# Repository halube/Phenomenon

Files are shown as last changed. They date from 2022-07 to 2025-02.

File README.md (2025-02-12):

# Phenomenon - Low-cost and multi-sensor system for automated phenotyping of plant in vitro culture
This is the official code implementation and used hardware of our paper, which is currently under a journal review:

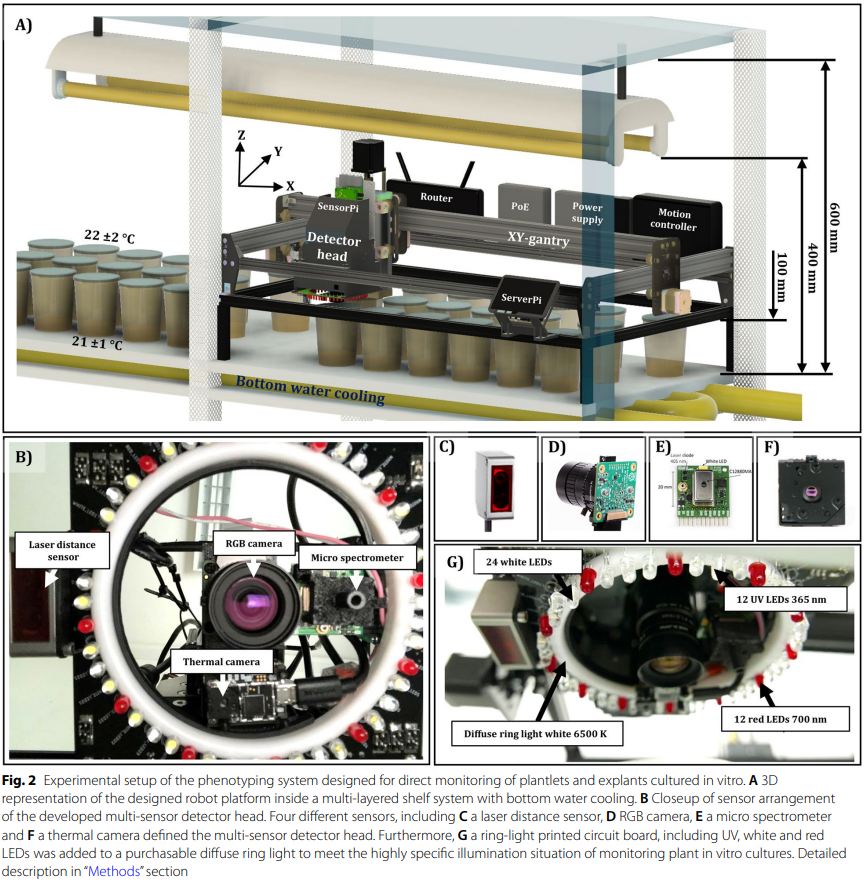
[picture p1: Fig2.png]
Robot


The main mechanical components of the system were:
- OpenBuilds ACRO 1515 60" x 60" (XY gantry)
- Openbuilds Linear Actuator (Z axis)

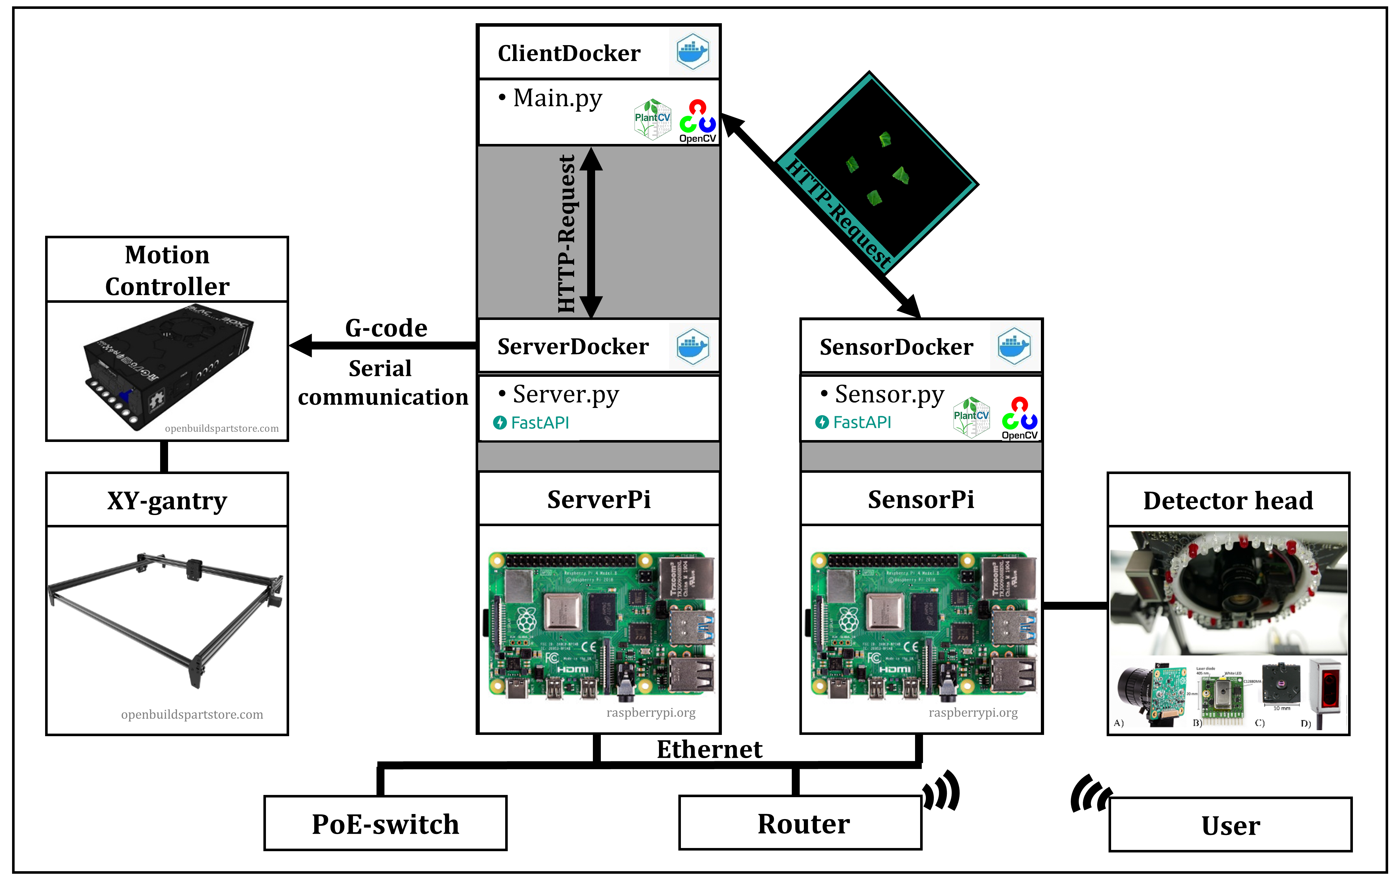
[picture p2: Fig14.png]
Software


Network connection & embedded system:
- Router & PoE-Switch
- 2 x Raspberry Pi 4B & PoE-Shield
- 2 x Wemos D1 Mini

Sensors of the system:
- RGB Raspberry Pi Camera High quality 12 MB with Edmund Optics 6mm low distortion lens equipied
- Thermal PureThermal 2 & Lepton 3.5
- Spectral µSpectrometer Hamamatsu C12880MA
- Depth Laser distance sensor OD-Mini OB1-B100

Hardware
- Containing 3D printable parts and PCB-Layouts

Software
- Containing Dockerfiles and Python scripts

Cite:
Bethge H, Winkelmann T, Lüdeke P, Rath T. Low-cost and automated phenotyping system “Phenomenon” for multi-sensor in situ monitoring in plant in vitro culture. Plant methods. 2023 May 2;19(1):42.

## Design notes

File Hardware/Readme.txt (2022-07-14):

Some of the 3D printed parts for cable chain were inspired by the build of "hilleke" & "dragonfire81m" 
(Thingiverse-User: https://www.thingiverse.com/thing:3110642; https://www.thingiverse.com/thing:2780302) but mainly also modified.

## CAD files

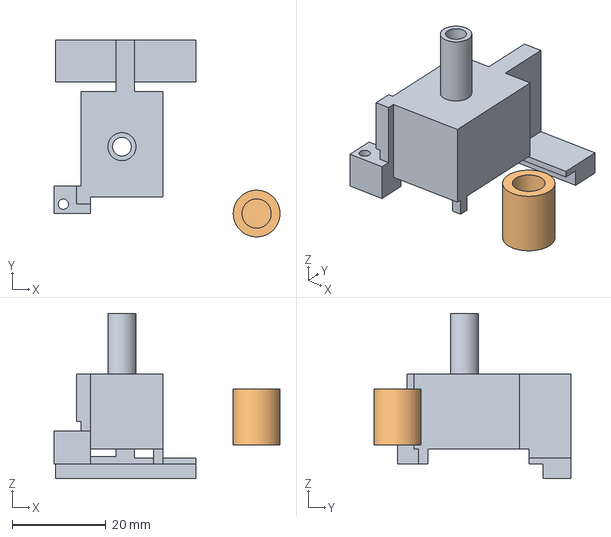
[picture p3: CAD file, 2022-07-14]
Hardware/MicroSpectrometer_Tube_aperature.step
48.2 x 42.0 x 35.3 mm

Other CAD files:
Hardware/X-Axis Cable chain and Motor retainer.f3d
Hardware/Y-Axis Cable chain retainer.f3d
Hardware/Y2-Axis Cable chain and Motor retainer.f3d

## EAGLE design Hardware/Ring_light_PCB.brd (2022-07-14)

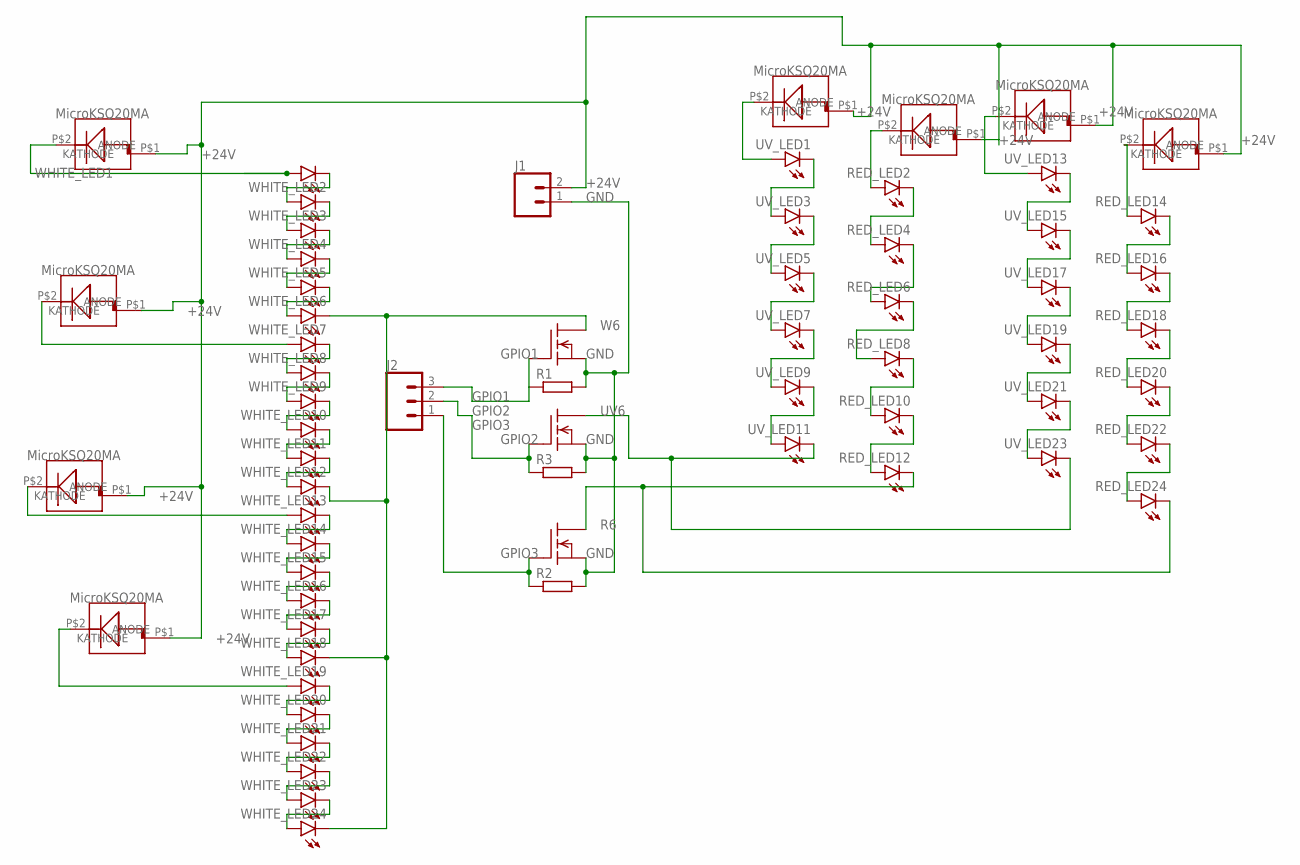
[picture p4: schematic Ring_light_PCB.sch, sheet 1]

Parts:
J1: CONN_025MM; SCREWTERMINAL-5MM-2
J2: CONN_03-SCREW-5MM; SCREWTERMINAL-5MM-3
Q1, Q2, Q4: BUZ10; TO220
R1, R2, R3: R-EU_0204/7; 0204/7
RED_LED2, RED_LED4, RED_LED6, RED_LED8, RED_LED10, RED_LED12, RED_LED14, RED_LED16, RED_LED18, RED_LED20, RED_LED22, RED_LED24: LED5MM
U$1, U$2, U$3, U$4, U$5, U$6, U$7, U$8: MICROKSQ220MA; MICROKSQ20MA
UV_LED1, UV_LED3, UV_LED5, UV_LED7, UV_LED9, UV_LED11, UV_LED13, UV_LED15, UV_LED17, UV_LED19, UV_LED21, UV_LED23: LED5MM
WHITE_LED1, WHITE_LED2, WHITE_LED3, WHITE_LED4, WHITE_LED5, WHITE_LED6, WHITE_LED7, WHITE_LED8, WHITE_LED9, WHITE_LED10, WHITE_LED11, WHITE_LED12, WHITE_LED13, WHITE_LED14, WHITE_LED15, WHITE_LED16, WHITE_LED17, WHITE_LED18, WHITE_LED19, WHITE_LED20, WHITE_LED21, WHITE_LED22, WHITE_LED23, WHITE_LED24: LED5MM

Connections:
+24V: J1.2, U$1.P$1 (KATHODE), U$2.P$1 (KATHODE), U$3.P$1 (KATHODE), U$4.P$1 (KATHODE), U$5.P$1 (KATHODE), U$6.P$1 (KATHODE), U$7.P$1 (KATHODE), U$8.P$1 (KATHODE)
GND: J1.1, Q1.3 (S), Q2.3 (S), Q4.3 (S), R1.2, R2.2, R3.2
GPIO1: J2.3, Q1.1 (G), R1.1
GPIO2: J2.2, Q2.1 (G), R3.1
GPIO3: J2.1, Q4.1 (G), R2.1
R0: RED_LED2.A, U$8.P$2 (ANODE)
R1: RED_LED2.K (C), RED_LED4.A
R2: RED_LED4.K (C), RED_LED6.A
R3: RED_LED6.K (C), RED_LED8.A
R4: RED_LED8.K (C), RED_LED10.A
R5: RED_LED10.K (C), RED_LED12.A
R6: Q4.2 (D), RED_LED12.K (C), RED_LED24.K (C)
R7: RED_LED14.A, U$6.P$2 (ANODE)
R8: RED_LED14.K (C), RED_LED16.A
R9: RED_LED16.K (C), RED_LED18.A
R10: RED_LED18.K (C), RED_LED20.A
R11: RED_LED20.K (C), RED_LED22.A
R12: RED_LED22.K (C), RED_LED24.A
UV0: U$7.P$2 (ANODE), UV_LED1.A
UV1: UV_LED1.K (C), UV_LED3.A
UV2: UV_LED3.K (C), UV_LED5.A
UV3: UV_LED5.K (C), UV_LED7.A
UV4: UV_LED7.K (C), UV_LED9.A
UV5: UV_LED9.K (C), UV_LED11.A
UV6: Q2.2 (D), UV_LED11.K (C), UV_LED23.K (C)
UV7: U$5.P$2 (ANODE), UV_LED13.A
UV8: UV_LED13.K (C), UV_LED15.A
UV9: UV_LED15.K (C), UV_LED17.A
UV10: UV_LED17.K (C), UV_LED19.A
UV11: UV_LED19.K (C), UV_LED21.A
UV12: UV_LED21.K (C), UV_LED23.A
W0: U$1.P$2 (ANODE), WHITE_LED1.A
W1: WHITE_LED1.K (C), WHITE_LED2.A
W2: WHITE_LED2.K (C), WHITE_LED3.A
W3: WHITE_LED3.K (C), WHITE_LED4.A
W4: WHITE_LED4.K (C), WHITE_LED5.A
W5: WHITE_LED5.K (C), WHITE_LED6.A
W6: Q1.2 (D), WHITE_LED6.K (C), WHITE_LED12.K (C), WHITE_LED18.K (C), WHITE_LED24.K (C)
W7: U$2.P$2 (ANODE), WHITE_LED7.A
W8: WHITE_LED7.K (C), WHITE_LED8.A
W9: WHITE_LED8.K (C), WHITE_LED9.A
W10: WHITE_LED9.K (C), WHITE_LED10.A
W11: WHITE_LED10.K (C), WHITE_LED11.A
W12: WHITE_LED11.K (C), WHITE_LED12.A
W13: U$3.P$2 (ANODE), WHITE_LED13.A
W14: WHITE_LED13.K (C), WHITE_LED14.A
W15: WHITE_LED14.K (C), WHITE_LED15.A
W16: WHITE_LED15.K (C), WHITE_LED16.A
W17: WHITE_LED16.K (C), WHITE_LED17.A
W18: WHITE_LED17.K (C), WHITE_LED18.A
W19: U$4.P$2 (ANODE), WHITE_LED19.A
W20: WHITE_LED19.K (C), WHITE_LED20.A
W21: WHITE_LED20.K (C), WHITE_LED21.A
W22: WHITE_LED21.K (C), WHITE_LED22.A
W23: WHITE_LED22.K (C), WHITE_LED23.A
W24: WHITE_LED23.K (C), WHITE_LED24.A

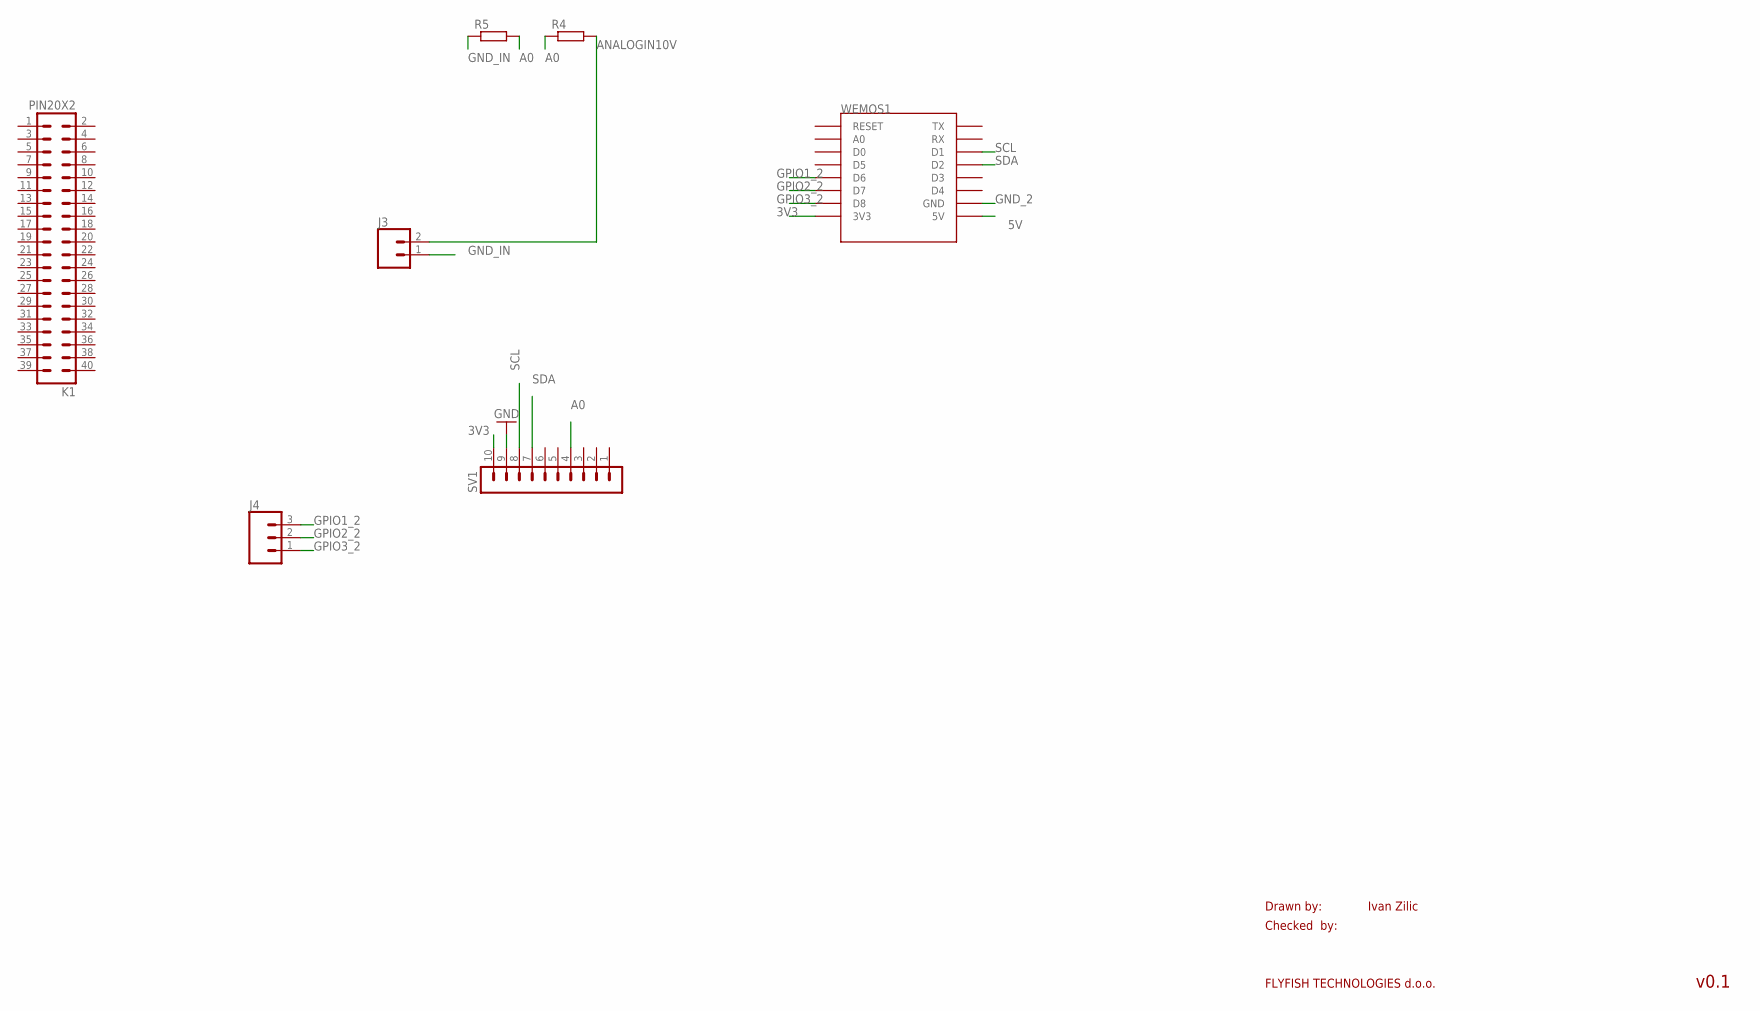
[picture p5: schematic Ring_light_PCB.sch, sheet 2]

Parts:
J3: CONN_025MM; SCREWTERMINAL-5MM-2
J4: CONN_03-SCREW-5MM; SCREWTERMINAL-5MM-3
K1: PIN20X2; PIN_20X2
R4, R5: R-EU_0204/7; 0204/7
SV1: MA10-1
WEMOS1: WEMOS-D1-MINI

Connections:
3V3: SV1.10, WEMOS1.3V3
5V: WEMOS1.5V
A0: R4.1, R5.2, SV1.4
ANALOGIN10V: J3.2, R4.2
GND_2: SV1.9, WEMOS1.GND
GND_IN: J3.1, R5.1
GPIO1_2: J4.3, WEMOS1.D6
GPIO2_2: J4.2, WEMOS1.D7
GPIO3_2: J4.1, WEMOS1.D8
SCL: SV1.8, WEMOS1.D1
SDA: SV1.7, WEMOS1.D2

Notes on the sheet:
Drawn by:
Checked by:
FLYFISH TECHNOLOGIES d.o.o.
Ivan Zilic
v0.1

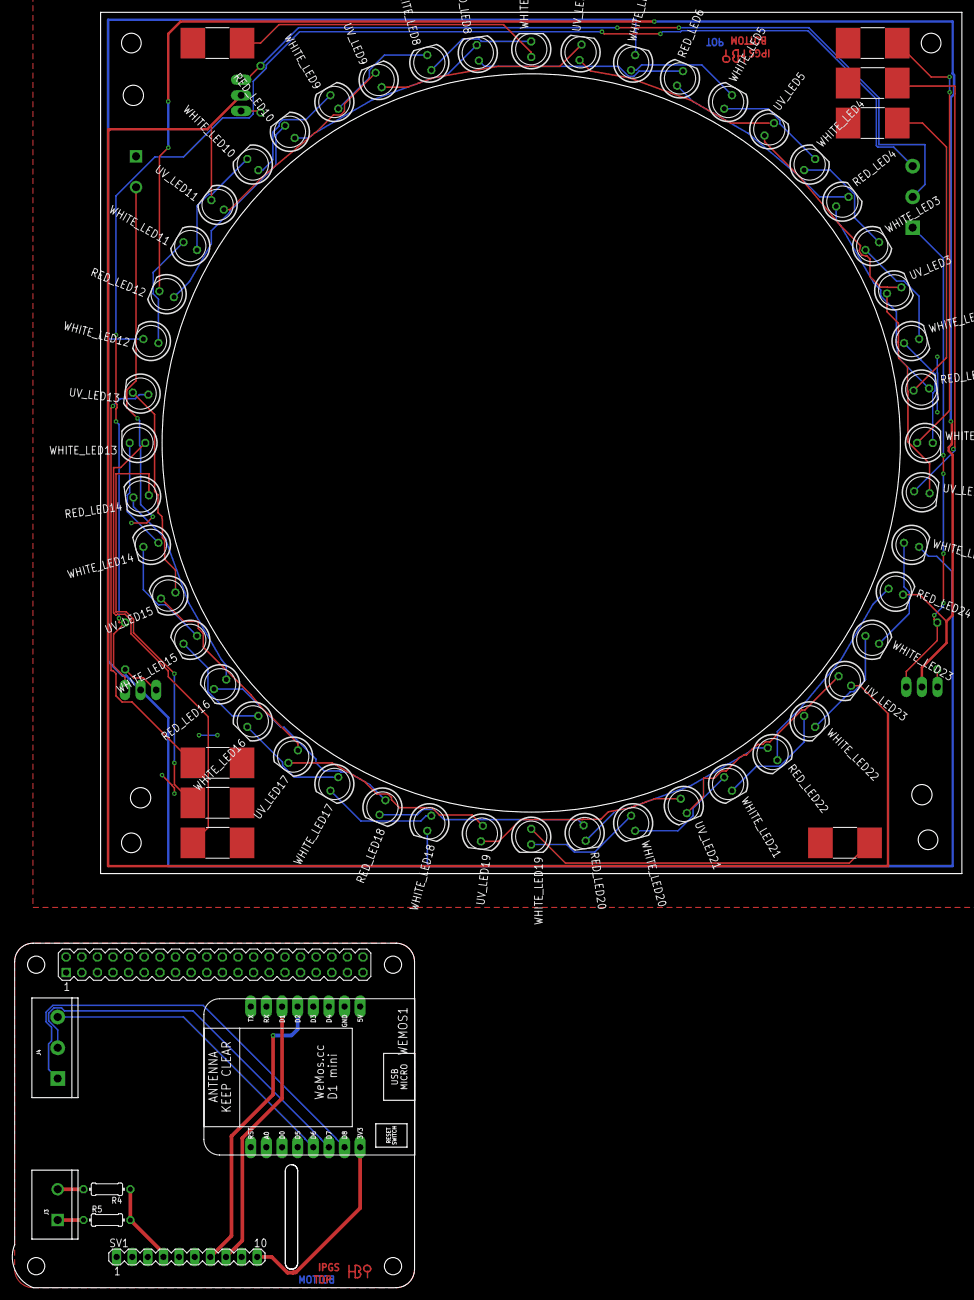
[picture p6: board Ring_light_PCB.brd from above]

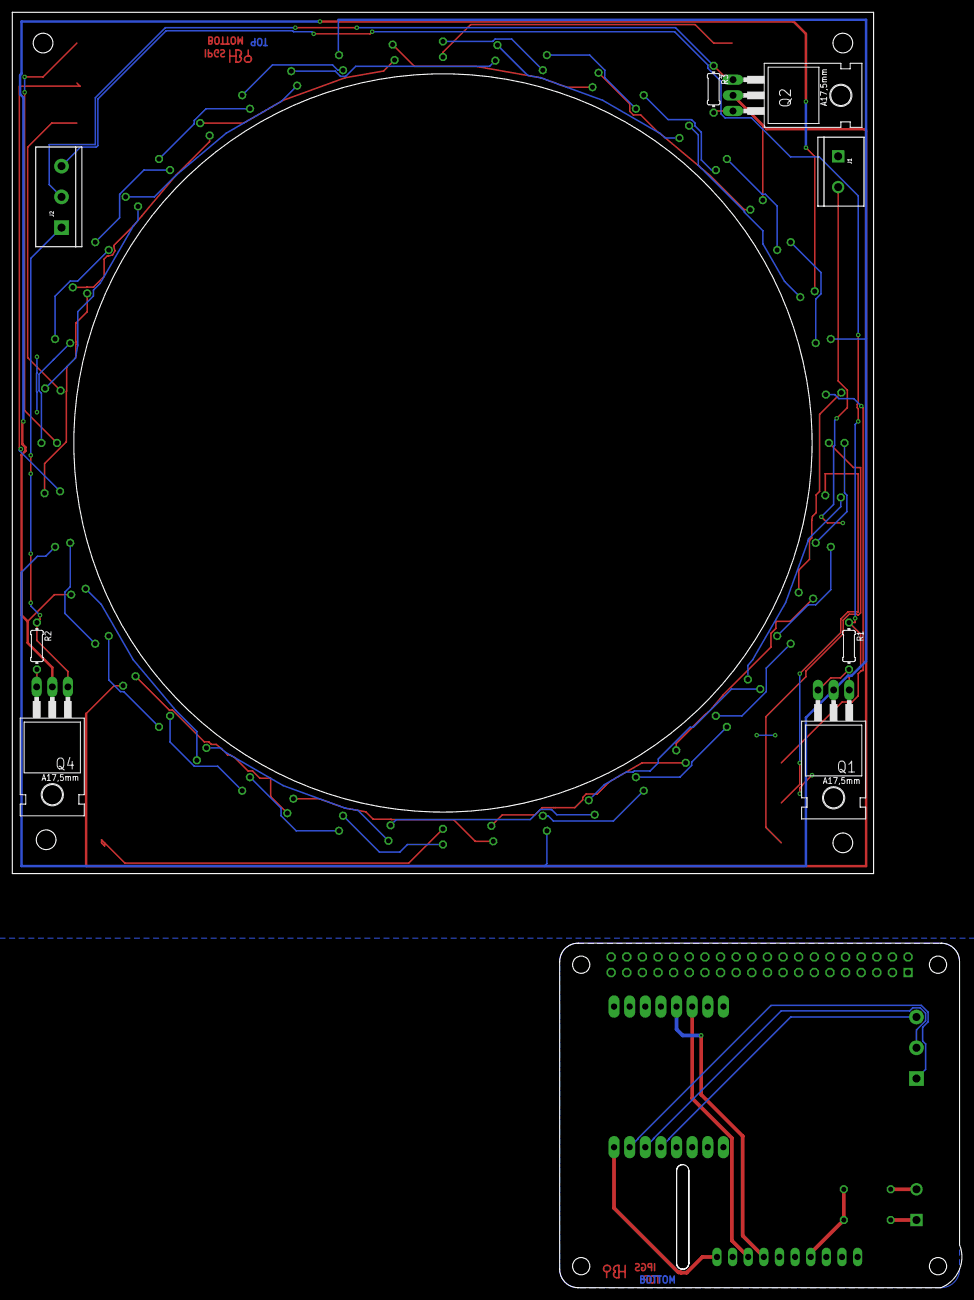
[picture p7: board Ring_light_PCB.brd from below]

Board: 2 copper layers, 140.0 x 140.0 mm, 71 parts (8 on the bottom side), 66 nets.

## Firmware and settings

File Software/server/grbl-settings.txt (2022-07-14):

$0=10  ;  Step pulse time, microseconds
$1=255  ;  Step idle delay, milliseconds
$2=0  ;  Step pulse invert, mask
$3=1  ;  Step direction invert, mask
$4=1  ;  Invert step enable pin, boolean
$5=0  ;  Invert limit pins, boolean
$6=0  ;  Invert probe pin, boolean
$10=1  ;  Status report options, mask
$11=0.020  ;  Junction deviation, millimeters
$12=0.002  ;  Arc tolerance, millimeters
$13=0  ;  Report in inches, boolean
$20=0  ;  Soft limits enable, boolean
$21=1  ;  Hard limits enable, boolean
$22=1  ;  Homing cycle enable, boolean
$23=3  ;  Homing direction invert, mask
$24=100.000  ;  Homing locate feed rate, mm/min
$25=1000.000  ;  Homing search seek rate, mm/min
$26=250  ;  Homing switch debounce delay, milliseconds
$27=5.000  ;  Homing switch pull-off distance, millimeters
$30=1000  ;  Maximum spindle speed, RPM
$31=0  ;  Minimum spindle speed, RPM
$32=0  ;  Laser-mode enable, boolean
$100=53.333  ;  X-axis steps per millimeter
$101=53.333  ;  Y-axis steps per millimeter
$102=200.000  ;  Z-axis steps per millimeter
$110=2500.000  ;  X-axis maximum rate, mm/min
$111=2500.000  ;  Y-axis maximum rate, mm/min
$112=1500.000  ;  Z-axis maximum rate, mm/min
$120=150.000  ;  X-axis acceleration, mm/sec^2
$121=150.000  ;  Y-axis acceleration, mm/sec^2
$122=50.000  ;  Z-axis acceleration, mm/sec^2
$130=660.000  ;  X-axis maximum travel, millimeters
$131=230.000  ;  Y-axis maximum travel, millimeters
$132=60.000  ;  Z-axis maximum travel, millimeters

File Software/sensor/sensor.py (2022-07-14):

#### Sensor.py description####
#### Author: Hans Bethge and Patrick Lüdeke
#### Description: Read sensors with Raspberry Pi 4 and network access of these function & data via FastAPI 
#### Required libraries:
from fastapi import FastAPI, HTTPException
from fastapi.middleware.cors import CORSMiddleware
from time import sleep
from fastapi.logger import logger
from picamera import PiCamera
from datetime import datetime, timedelta
from fastapi.responses import FileResponse, JSONResponse
import picamera
from picamera import mmal, mmalobj, exc
from picamera.mmalobj import to_rational
import time
import logging
import glob
import serial
import cv2
import numpy as np
from flirpy.camera.lepton import Lepton

try:
  from queue import Queue
except ImportError:
  from Queue import Queue
import platform


#### Set PiCamera HQ Gain controll
#### Credits to github.com/rwb27/set_picamera_gain.py
MMAL_PARAMETER_ANALOG_GAIN = mmal.MMAL_PARAMETER_GROUP_CAMERA + 0x59
MMAL_PARAMETER_DIGITAL_GAIN = mmal.MMAL_PARAMETER_GROUP_CAMERA + 0x5A
def setCameraGain(camera, gain, value):
    """Set the analog gain of a PiCamera.
    camera: the picamera.PiCamera() instance you are configuring
    gain: either MMAL_PARAMETER_ANALOG_GAIN or MMAL_PARAMETER_DIGITAL_GAIN
    value: a numeric value that can be converted to a rational number.
    """
    if gain not in [MMAL_PARAMETER_ANALOG_GAIN, MMAL_PARAMETER_DIGITAL_GAIN]:
        raise ValueError("The gain parameter was not valid")
    ret = mmal.mmal_port_parameter_set_rational(camera._camera.control._port, 
                                                    gain,
                                                    to_rational(value))
    if ret == 4:
        raise exc.PiCameraMMALError(ret, "Are you running the latest version of the userland libraries? Gain setting was introduced in late 2017.")
    elif ret != 0:
        raise exc.PiCameraMMALError(ret)

def setCameraAnalogGain(camera, value):
    """Set the gain of a PiCamera object to a given value."""
    setCameraGain(camera, MMAL_PARAMETER_ANALOG_GAIN, value)

def setCameraDigitalGain(camera, value):
    """Set the digital gain of a PiCamera object to a given value."""
    setCameraGain(camera, MMAL_PARAMETER_DIGITAL_GAIN, value)
#### Initialize PiCamera HQ with corresponsing device settings
def camera_initializing():
   camera.resolution = (4054, 3040) 
   time.sleep(1)
   camera.awb_mode = 'off'
   time.sleep(1)
   camera.awb_gains = (3.3,1.5) #### Fixed Gain settings (R,B)
   camera.exposure_mode = 'off'
   time.sleep(1)
   camera.shutter_speed = 2500
   time.sleep(1)
   print("Attempting to set analogue gain to 1")
   setCameraAnalogGain(camera, 1)
   print("Attempting to set digital gain to 1")
   setCameraDigitalGain(camera, 1)
   sleep(2)

def takePhoto(name):
   camera.capture('./' + name)

def takeNPArrayImage(name):
    #### Capture Image as NP-Array
    output = np.empty((3040 * 4064 * 3,), dtype=np.uint8)
    camera.capture(output, 'bgr')
    output = output.reshape(3040, 4064, 3)
    output = output[:3040, :4054, :]
    cv2.imwrite('./temp.png', output)

camera = PiCamera()
camera_initializing()


gunicorn_logger = logging.getLogger('gunicorn.error')
logger.handlers = gunicorn_logger.handlers
if __name__ != "main":
    logger.setLevel(gunicorn_logger.level)
else:
    logger.setLevel(logging.DEBUG)

app = FastAPI()

app.add_middleware(
    CORSMiddleware,
    allow_origins=["*"],
    allow_credentials=True,
    allow_methods=["*"],
    allow_headers=["*"],
)

#### Identification of peripheral USB-Controller (Wemos with Laser-Distance-Sensor and other light sources)
wemosSerial = None
def getWemosSerial():
    global wemosSerial
    if wemosSerial != None:
        print("wemosSerial is none")
        wemosSerial.write(b"WHO.IS?\n")
        deviceName = wemosSerial.readline()
        print(deviceName)
        if deviceName.startswith(b'LIGHT AND LASER'):
            return wemosSerial

    print(glob.glob("/dev/ttyUSB*"))
    for device in glob.glob("/dev/ttyUSB*"):
        try:
            print(device)
            currentDevice = serial.Serial(device,115200)
            currentDevice.write(b"WHO.IS?\n")
            deviceName = currentDevice.readline()
            print(deviceName)
            if deviceName.startswith(b'LIGHT AND LASER'):
                print("Found device")
                wemosSerial = currentDevice
                return wemosSerial
        except Exception as e:
            print(e)
            continue

    raise HTTPException(status_code=500, detail="Wemos USB Device for Distance sensor and Ring light not found!")

#### Identification of peripheral USB-Controller (Wemos with Mini-Spectrometer)
specSerial = None
def getSpecSerial():
    global specSerial

    if specSerial != None:
        print("specSerial is none")
        specSerial.write(b"WHO.IS?\n")
        deviceName = specSerial.readline()
        print(deviceName)
        if deviceName.startswith(b'SPECTROMETER'):
            return specSerial

    print(glob.glob("/dev/ttyUSB*"))
    for device in glob.glob("/dev/ttyUSB*"):
        try:
            print(device)
            currentDevice = serial.Serial(device,115200)
            currentDevice.write(b"WHO.IS?\n")
            deviceName = currentDevice.readline()
            print(deviceName)
            if deviceName.startswith(b'SPECTROMETER'):
                print("Found device")
                specSerial = currentDevice
                return specSerial
        except Exception as e:
            print(e)
            continue

    raise HTTPException(status_code=500, detail="Spectrometer USB Device not found!")
    
#### Identification of peripheral USB-Controller (PureThermal-Board)
def getThermalDevice():
    for i in range(1,11,1):
        cv2_cap = cv2.VideoCapture(i)
        print("Camera video port:", i)
        if cv2_cap.isOpened():
            return cv2_cap
    raise HTTPException(status_code=500, detail="Thermal Camera USB Device not found!")

def setSpecWhiteLED(turnOn, serial):
   #### Turn White LED of Spectrometer/C128880 Breakout Board on/off
   if turnOn:
      serial.write(str.encode("SPEC.WHITE_LED? 1\n"))
   else:
      serial.write(str.encode("SPEC.WHITE_LED? 0\n"))

def setSpecUVLED(turnOn, serial):
   #### Turn UV LED of Spectrometer/C128880 Breakout Board on/off
   if turnOn:
      serial.write(str.encode("SPEC.UV_LED? 1\n"))
   else:
      serial.write(str.encode("SPEC.UV_LED? 0\n"))

def setLightWhiteLED(turnOn, serial):
   #### Turn White LEDs of Ringlight on/off
   if turnOn:
      serial.write(str.encode("LIGHT.WHITE_LED? 1\n"))
   else:
      serial.write(str.encode("LIGHT.WHITE_LED? 0\n"))

def setLightUVLED(turnOn, serial):
   #### Turn UV LEDs of Ringlight on/off
   if turnOn:
      serial.write(str.encode("LIGHT.UV_LED? 1\n"))
   else:
      serial.write(str.encode("LIGHT.UV_LED? 0\n"))
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

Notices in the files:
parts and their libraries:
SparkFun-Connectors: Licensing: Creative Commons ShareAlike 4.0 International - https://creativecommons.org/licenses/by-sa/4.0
